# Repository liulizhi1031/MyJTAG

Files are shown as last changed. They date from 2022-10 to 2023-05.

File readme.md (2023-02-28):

# **MyJTAG**

- ## 简介

本项目使用Digilent JTAG方案，使用FT2232HL芯片构建定制化的JTAG模块，提供一路JTAG调试接口与一路串口。

- ## 固件烧写

本人使用VMware16 + Ubuntu16.04.4进行固件烧写。

首先在Ubuntu下安装ftdi_eeprom工具：

```bash
sudo apt-get install ftdi_eeprom
```

然后将bin文件夹内的两个文件复制到虚拟机中，输入以下命令完成烧写：

```bash
sudo ftdi_eeprom --flash-eeprom flash_digilent_smt1.conf
```

注意：要确保设备连接至虚拟机而非主机，如烧写失败可尝试重新插拔并重试。

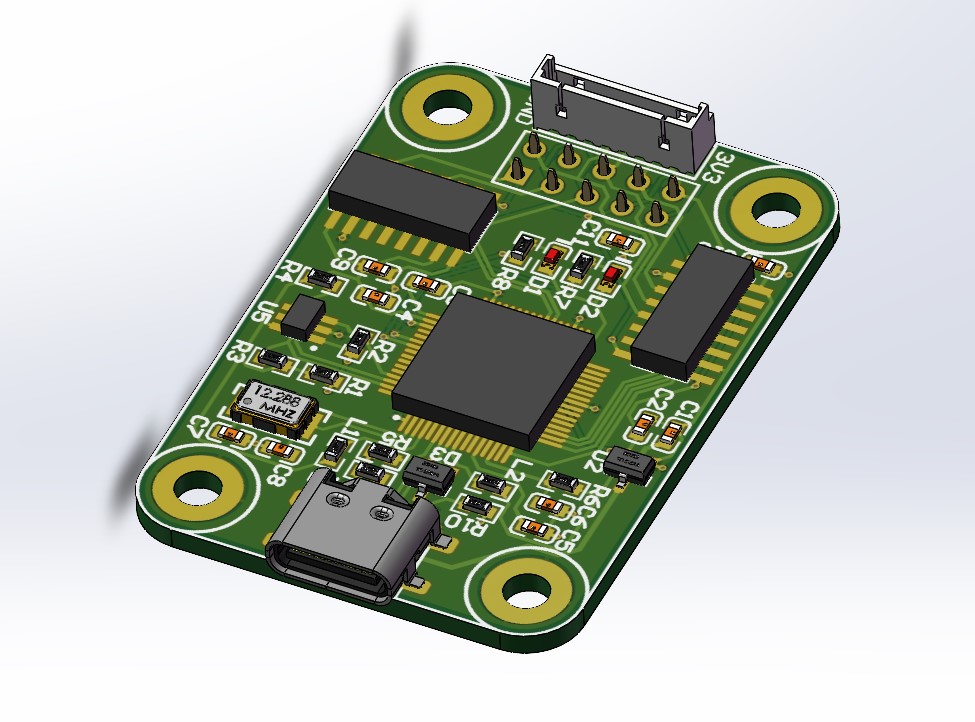
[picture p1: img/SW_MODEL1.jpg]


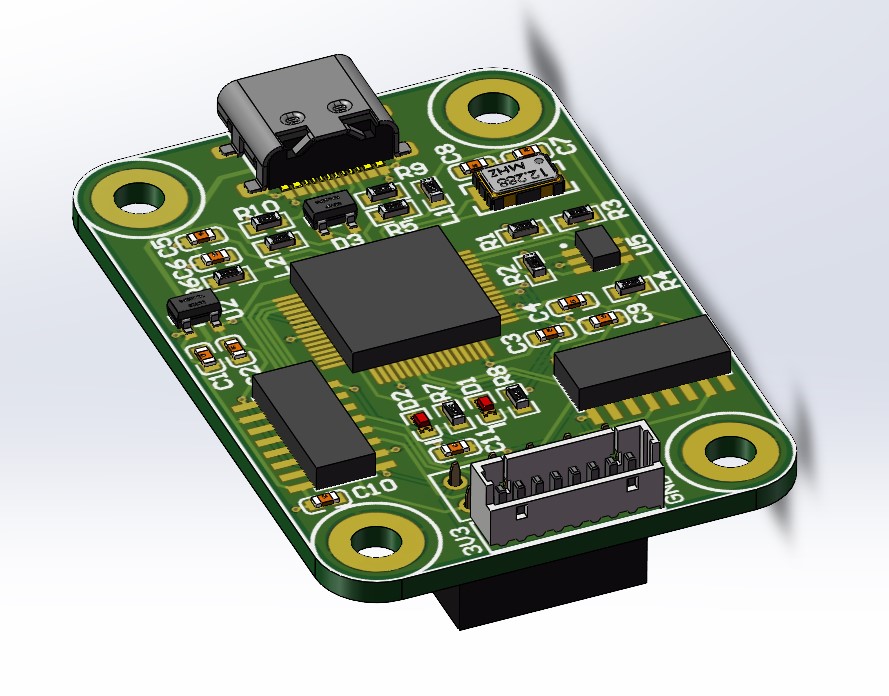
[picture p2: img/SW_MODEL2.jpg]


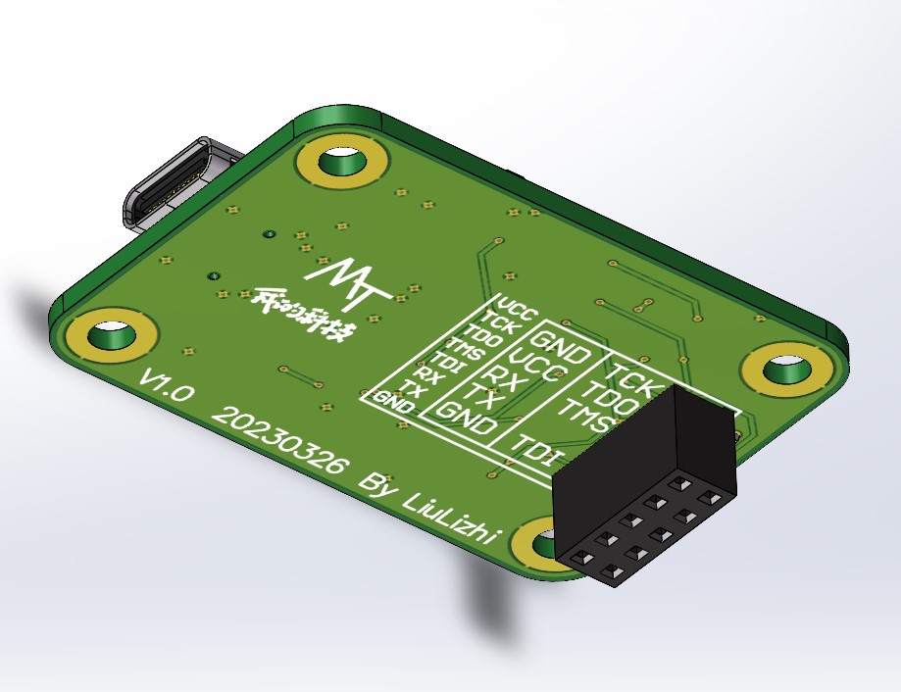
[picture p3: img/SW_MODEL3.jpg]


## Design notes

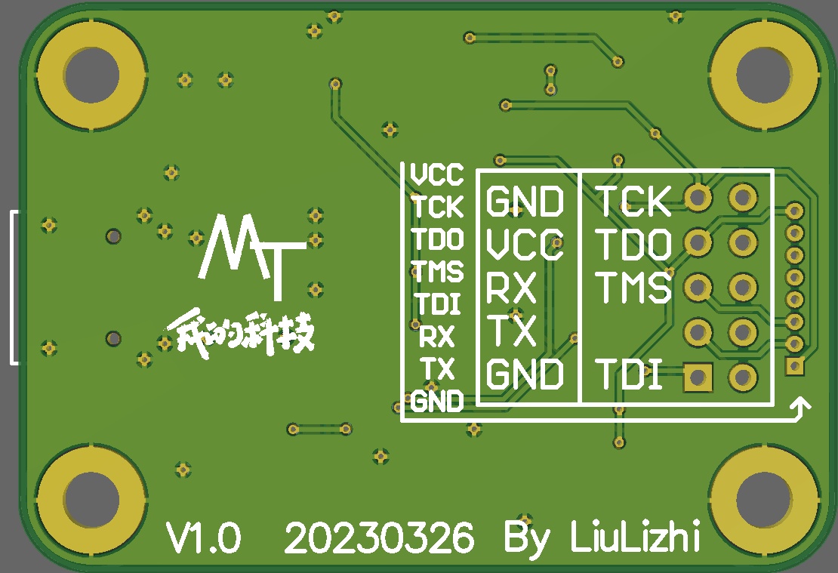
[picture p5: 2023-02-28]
img/myjtag_down.jpg

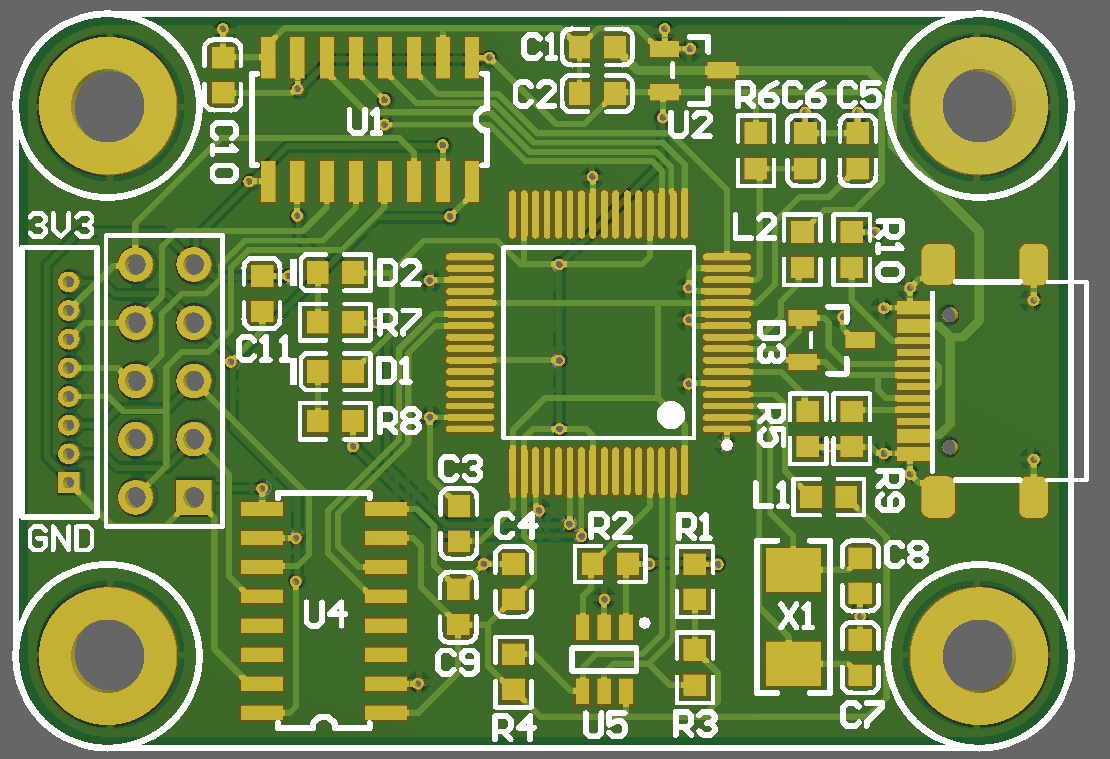
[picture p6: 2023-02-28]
img/myjtag_up.jpg

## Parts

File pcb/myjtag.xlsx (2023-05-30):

Comment | Designator | Footprint | Quantity | LibRef | Description
10UF | C1, C2, C5 | 0603_C | 3 | 0603_CAP
104 | C3, C4, C9, C10, C11 | 0603_C | 5 | 0603_CAP
10NF | C6 | 0603_C | 1 | 0603_CAP
22PF | C7, C8 | 0603_C | 2 | 0603_CAP
0603_LED | D1, D2 | 0603_LED | 2 | 0603_LED
ESD5302 | D3 | SOT23 | 1 | PESD5V2S2UT | ESD DIODE
SH1.25mm_8P | H1 | SH1.25MM_8P | 1 | SH1.25mm_8P
Header_2.54_5P_2 | H2 | HDR2_5P | 1 | Header_2.54_5P_2
USB_C | H3 | USB_C_16PIN_SMT | 1 | USB_C_16P_SMT
600R1A | L1, L2 | 0603_R | 2 | 0603_BeadCore | Bead core
10K | R1, R3, R4, R6 | 0603_R | 4 | 0603_RES
2K | R2, R7, R8 | 0603_R | 3 | 0603_RES
12K | R5 | 0603_R | 1 | 0603_RES
5K1 | R9, R10 | 0603_R | 2 | 0603_RES
CA-IS3741 | U1, U4 | SOIC16N | 2 | CA-IS3741
3.3V | U2 | SOT23 | 1 | LDO_XC6206P332MR | 线性稳压器
FT2232H | U3 | LQFP64 | 1 | FT2232H
93LC56BT | U5 | SOT_23_6 | 1 | 93LC56BT
12MHz | X1 | XTAL_5032 | 1 | XTAL_5032 | 贴片无源晶振

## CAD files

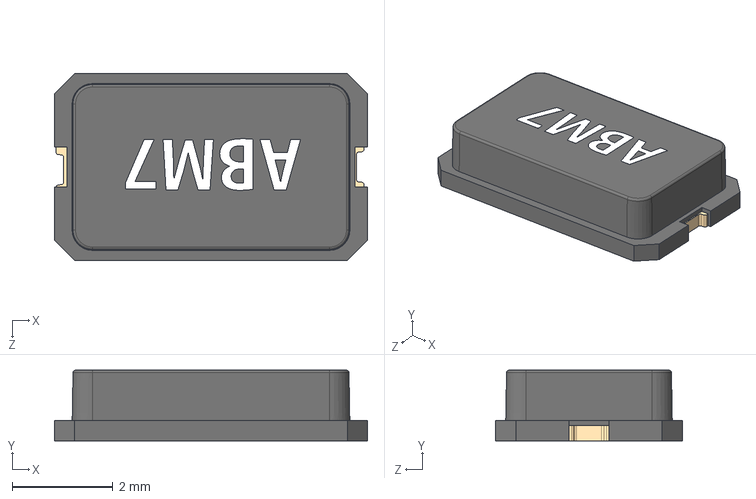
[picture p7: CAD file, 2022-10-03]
doc/ft2232hl-jtag-clone-main/Hardware/JTAG_HW_FT2232HL/3D/Xtal-ABM7.STEP
6.20 x 1.40 x 3.70 mm
abm7case
abm7pad x 2

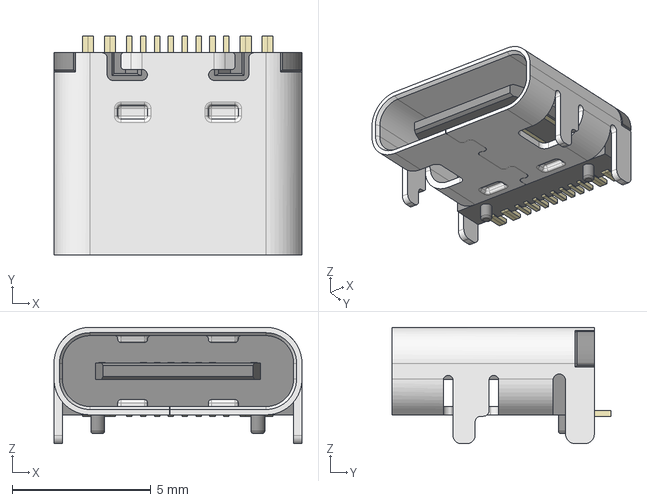
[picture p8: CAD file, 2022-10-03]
doc/ft2232hl-jtag-clone-main/Hardware/kicad-USB-C-master/HRO_TYPE-C-31-M-12.step
8.95 x 7.90 x 4.20 mm

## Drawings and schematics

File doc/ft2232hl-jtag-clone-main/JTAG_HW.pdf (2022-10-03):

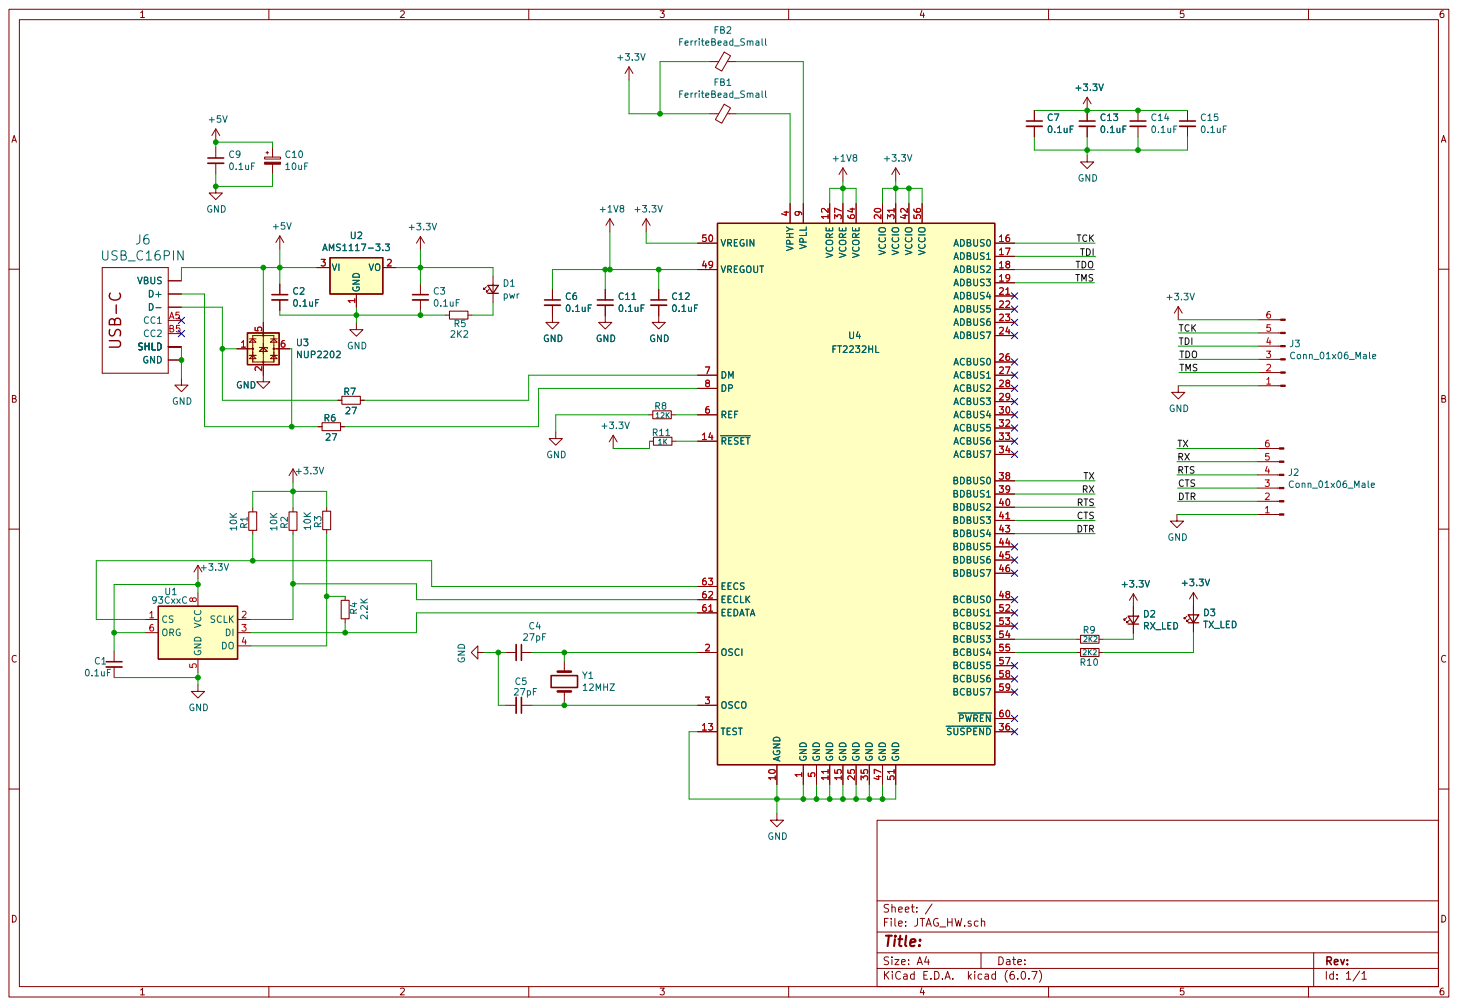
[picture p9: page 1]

1 AGND 10 GND 11 VCORE 12 TEST 13 ~{RESET} 14 GND 15 ADBUS0 16 ADBUS1 17 ADBUS2 18 ADBUS3 19 OSCI 2 VCCIO 20 ADBUS4 21 ADBUS5 22 ADBUS6 23 ADBUS7 24 GND 25 ACBUS0 26 ACBUS1 27 ACBUS2 28 ACBUS3 29 OSCO 3 ACBUS4 30 VCCIO 31 ACBUS5 32 ACBUS6 33 ACBUS7 34 GND 35

4 BDBUS2 40 BDBUS3 41 VCCIO 42 BDBUS4 43 BDBUS5 44 BDBUS6 45 BDBUS7 46 GND 47 BCBUS0 48 VREGOUT 49 GND

5 VREGIN 50 GND 51 BCBUS1 52 BCBUS2 53 BCBUS3 54 BCBUS4 55 VCCIO 56 BCBUS5 57 BCBUS6 58 BCBUS7 59 REF 6 ~{PWREN} 60 EEDATA 61 EECLK 62 EECS 63 VCORE 64 DM 7 DP 8 VPLL

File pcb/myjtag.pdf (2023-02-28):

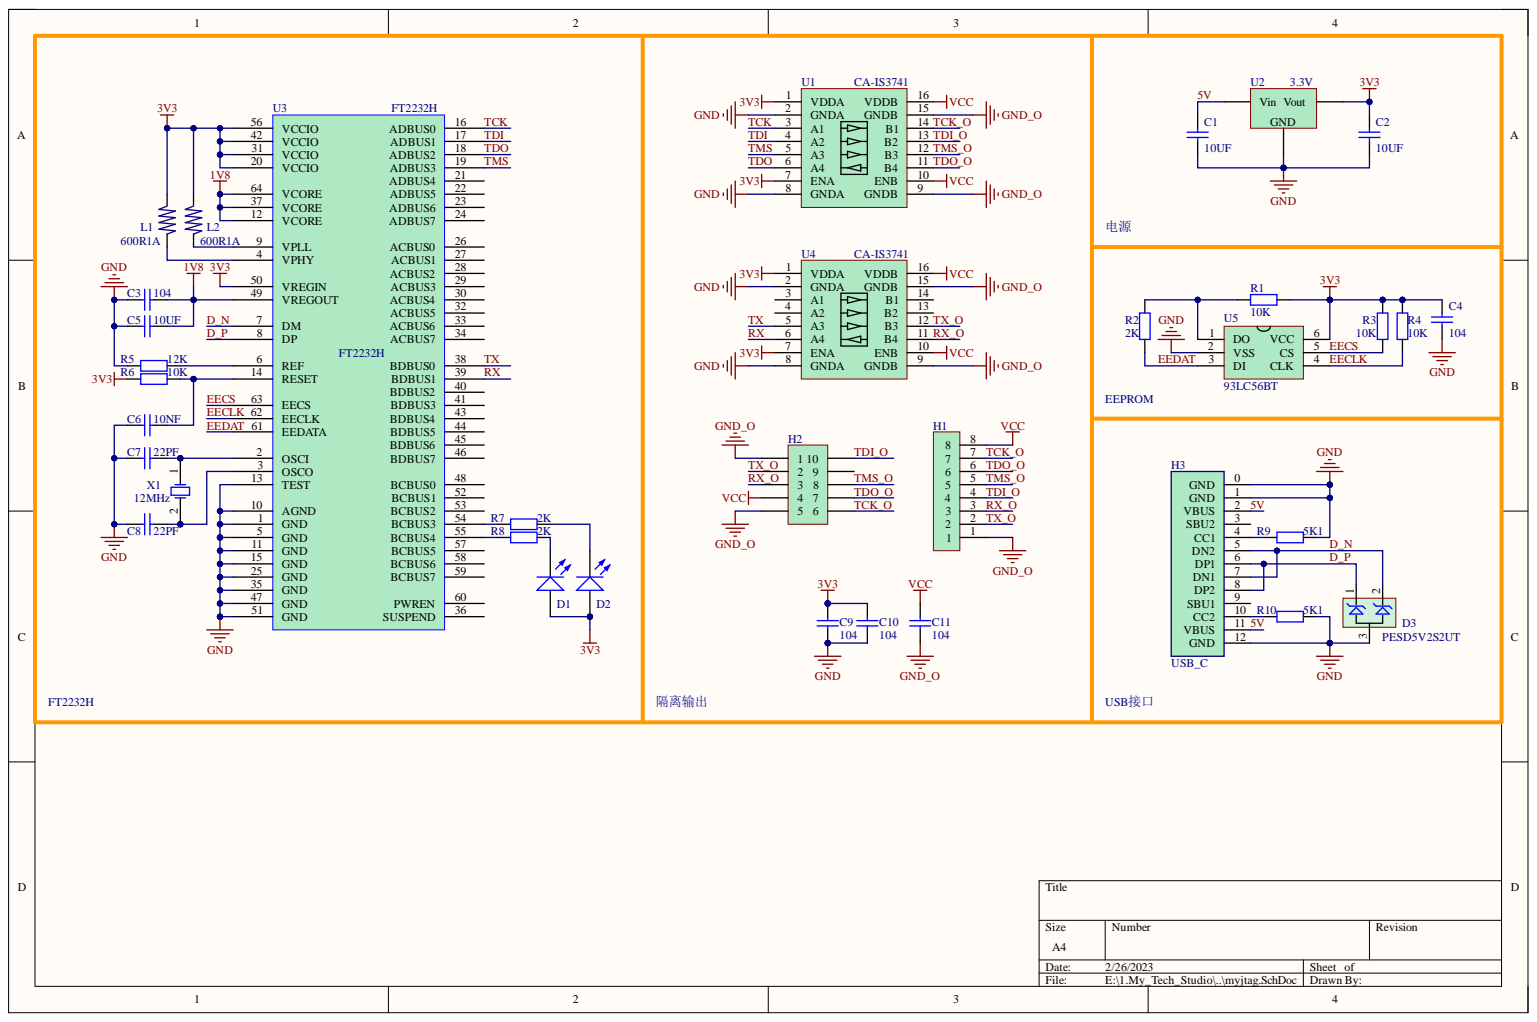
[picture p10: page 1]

4 7
5 1

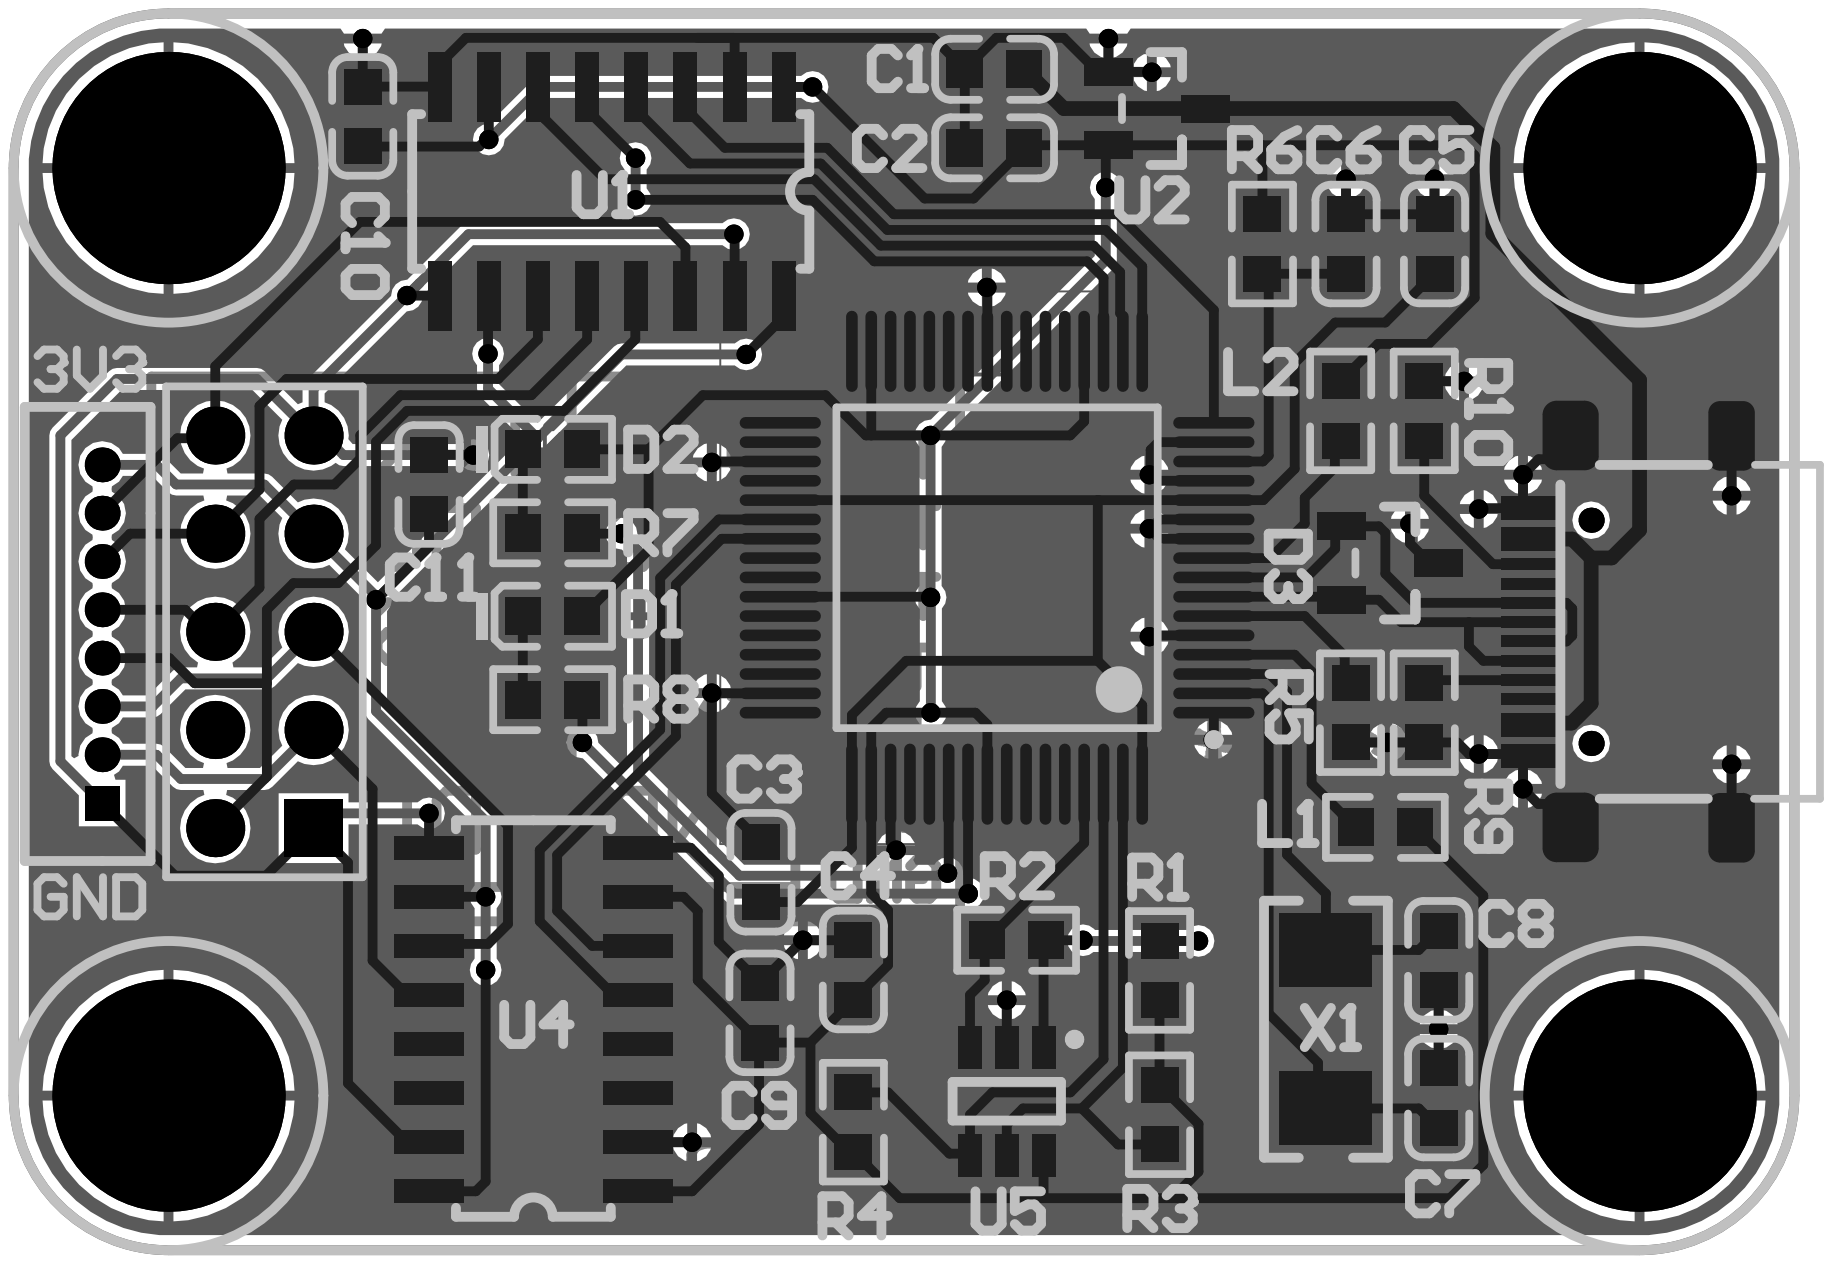
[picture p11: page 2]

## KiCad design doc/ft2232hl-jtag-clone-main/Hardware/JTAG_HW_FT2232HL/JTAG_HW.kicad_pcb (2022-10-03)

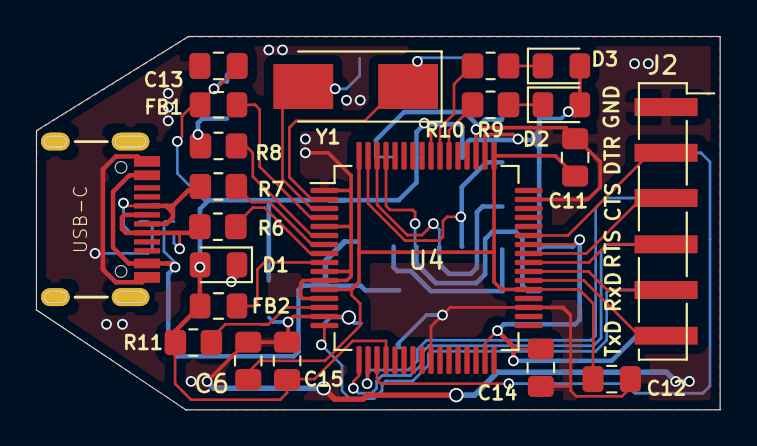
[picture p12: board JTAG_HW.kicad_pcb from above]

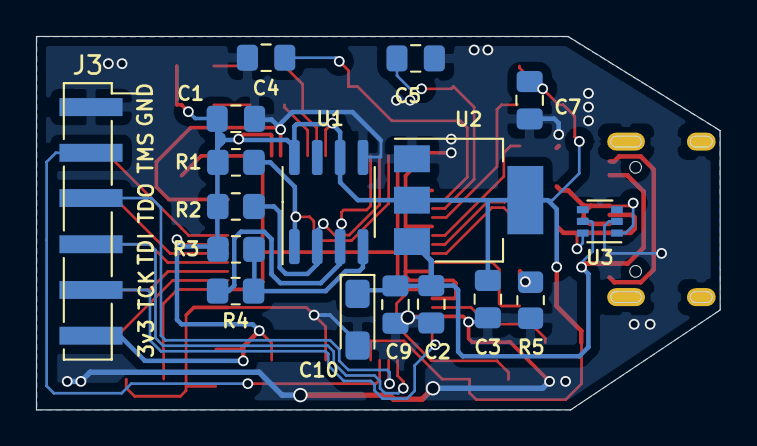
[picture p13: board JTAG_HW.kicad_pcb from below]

Board: 2 copper layers, 38.0 x 20.7 mm, 38 parts (17 on the bottom side), 32 nets.

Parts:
C1, C2, C3, C6, C7, C9, C11, C12, C13, C14, C15: 0.1uF; C_0805_2012Metric_Pad1.18x1.45mm_HandSolder
C4, C5: 27pF; C_0805_2012Metric_Pad1.18x1.45mm_HandSolder
C10: 10uF; CP_EIA-3216-18_Kemet-A_Pad1.58x1.35mm_HandSolder
D1: pwr; LED_0805_2012Metric_Pad1.15x1.40mm_HandSolder
D2: RX_LED; LED_0805_2012Metric_Pad1.15x1.40mm_HandSolder
D3: TX_LED; LED_0805_2012Metric_Pad1.15x1.40mm_HandSolder
FB1, FB2: FerriteBead_Small; L_0805_2012Metric_Pad1.15x1.40mm_HandSolder
J2, J3: Conn_01x06_Male; PinHeader_1x06_P2.54mm_Vertical_SMD_Pin1long
J6: USB_C16PIN; USB-C-COM-15111
R1, R2, R3: 10K; R_0805_2012Metric_Pad1.20x1.40mm_HandSolder
R4: 2.2K; R_0805_2012Metric_Pad1.20x1.40mm_HandSolder
R5, R9, R10: 2K2; R_0805_2012Metric_Pad1.20x1.40mm_HandSolder
R6, R7: 27; R_0805_2012Metric_Pad1.20x1.40mm_HandSolder
R8: 12K; R_0805_2012Metric_Pad1.20x1.40mm_HandSolder
R11: 1K; R_0805_2012Metric_Pad1.20x1.40mm_HandSolder
U1: 93CxxC; SOIC-8_3.9x4.9mm_P1.27mm
U2: AMS1117-3.3; SOT-223-3_TabPin2
U3: NUP2202; SOT-363_SC-70-6
U4: FT2232HL; LQFP-64_10x10mm_P0.5mm
Y1: 12MHZ; Crystal_SMD_0603-2Pin_6.0x3.5mm_HandSoldering

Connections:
+1V8: C6.1, C11.1, C12.1, U4.12, U4.37, U4.49, U4.64
+3V3: C1.1, C3.1, C7.1, C13.1, C14.1, C15.1, D1.2, D2.2, D3.2, FB1.2, FB2.2, J3.6, R1.2, R2.2, R3.2, R11.1, U1.6, U1.8, U2.2, U4.20, U4.31, U4.42, U4.50, U4.56
+5V: C2.1, C9.1, C10.1, J6.VBUS1, J6.VBUS2, U2.3, U3.5
/CTS: J2.3, U4.41
/DTR: J2.2, U4.43
/RTS: J2.4, U4.40
/RX: J2.5, U4.39
/TCK: J3.5, U4.16
/TDI: J3.4, U4.17
/TDO: J3.3, U4.18
/TMS: J3.2, U4.19
/TX: J2.6, U4.38
GND: C1.2, C2.2, C3.2, C4.2, C5.2, C6.2, C7.2, C9.2, C10.2, C11.2, C12.2, C13.2, C14.2, C15.2, J2.1, J3.1, J6.GND, J6.GND2, J6.SHLD1, J6.SHLD2, J6.SHLD3, J6.SHLD4, J6.SHLD5, J6.SHLD6, J6.SHLD7, J6.SHLD8, R5.2, R8.1, U1.5, U2.1, U3.2, U4.1, U4.5, U4.10, U4.11, U4.13, U4.15, U4.25, U4.35, U4.47, U4.51
unnamed: C4.1, U4.2, Y1.1
unnamed: C5.1, U4.3, Y1.2
unnamed: D1.1, R5.1
unnamed: D2.1, R9.1
unnamed: D3.1, R10.1
unnamed: FB1.1, U4.4
unnamed: FB2.1, U4.9
unnamed: J6.A6, J6.B6, R6.1, U3.6
unnamed: J6.A7, J6.B7, R7.1, U3.1
unnamed: R1.1, U1.1, U4.63
unnamed: R2.1, U1.2, U4.62
unnamed: R3.1, R4.1, U1.4
unnamed: R4.2, U1.3, U4.61
unnamed: R6.2, U4.8
unnamed: R7.2, U4.7
unnamed: R8.2, U4.6
unnamed: R9.2, U4.54
unnamed: R10.2, U4.55
unnamed: R11.2, U4.14

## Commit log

2022-10-03 add file first time
    [HRO_TYPE-C-31-M-12.step, JTAG_HW.kicad_pcb, JTAG_HW.kicad_sch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]
2023-02-28 20230228
    更新V1.0版本PCB设计
    [myjtag.PcbDoc, myjtag.PrjPCB, myjtag.SchDoc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]
2023-05-30 refactor: change TVS diode
    change TVS diode
    [myjtag.PcbDoc, myjtag.SchDoc, myjtag.xlsx]
